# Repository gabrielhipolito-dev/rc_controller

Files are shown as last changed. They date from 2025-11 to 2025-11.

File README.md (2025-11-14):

# Garden Assistant Bot (GAB)

This project includes a robot which uses a variety of sensors & motors to measure and provide data from your garden plants, as well as a user interface for communicating and controlling the robot.

---

##  Visual Overview of GAB Project

### WPF User Interface (UI)
<br>

<p align="center">
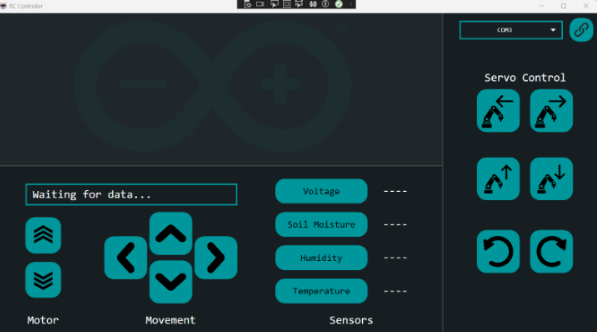
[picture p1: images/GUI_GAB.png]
WPF User Interface for Robot Control & Plant Monitoring
  
  <br>
  <em>Fig. 1 — WPF User Interface for Robot Control & Plant Monitoring</em><br>
  The UI provides control, Bluetooth connection status, and sensor data for soil moisture, temperature, and humidity.
</p>
<br><br>

### GAB  Overview
<br>

<p align="center">
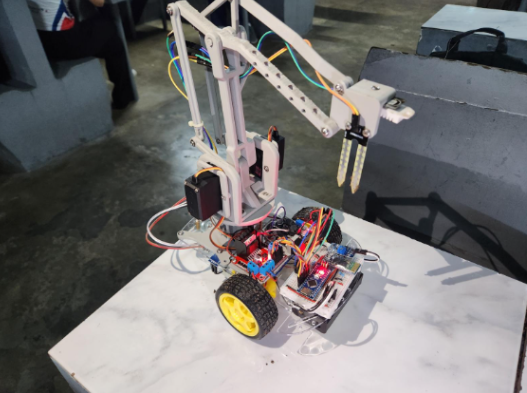
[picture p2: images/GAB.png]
View of Garden Assistant Bot (GAB)
    
  <br>
  <em>Fig. 2 — VIEW Garden Assistant Bot (GAB) Hardware</em><br>
  This figure displays the GAB, showing the sensor placements and main control board.
</p>
<br>

---
### Developed By
- Jeff Bayhon  
- Lance Dador  
- Giuliano de Guzman  
- Gabriel Hipolito  

---

## Languages Used
- **Arduino** (Nano microcontroller firmware)
- **C#** (Windows .NET Application)

---

## Features
- 2-Wheel Drive movement system  
- 4-DOF robotic servo arm  
- Bluetooth communication (Serial)  
- Live sensor readings:
  - Battery voltage  
  - Soil moisture  
  - Air humidity  
  - Air temperature  
- GUI desktop controller
- Keyboard controls for easy operation

---

## Requirements

### Software
- **Visual Studio 2022**
- **.NET 8**
- **Arduino IDE**

### Hardware
- Arduino Nano CH340 
- HC-05 Bluetooth Module 
- L298N Motor Driver 
- 3x MG996R Servo Motor 
- Voltage Sensor Module 
- DHT22 Sensor 
- L298N H-Bridge Driver
- HW-080 soil moisture sensor 
- 2x 18650 Battery Cell
- 2 cell 18650 battery holder
- Toggle Switch 
- Jumper Wires 

---

##  Folder Structure

```
/rc_controller
  └── /ARDUINO_NANO
      └── lupa_tusok_updated_ver.ino
  └── /img
  └── app.xaml
  └── app.xaml.cs
  └── AssemblyInfo.cs
  └── MainWindow.xaml
  └── MainWindow.xaml.cs
  └── rc_controller.csproj
```

## Steps to Connect and the Program

1. Clone the repository:

```bash
git clone https://github.com/YourRepoHere/rc_controller.git
cd rc_controller
```

2. Upload Arduino:

   * Open `/ARDUINO_NANO/lupa_tusok_updated_ver.ino` in Arduino IDE
   * Connect Arduino Nano via USB
   * Select board: `Tools → Board → Arduino Nano`
   * Select processor: `ATmega328P (Old Bootloader)` (for CH340)
   * Select COM port (example: COM5)
   * Click **Upload**
3. Run the Application(Visual Studio):

   * Open `rc_controller.csproj` in Visual Studio
   * Open `MainWindow.xaml`
   * Click **Start / Run** to launch the app
4. Connect to the RC Car:

   * Select Bluetooth COM port in the app
   * Click **Connect**
   * Use the GUI to drive the robot and monitor sensor data

## Notes

* Ensure the robot is powered **before** connecting the app
* Use correct COM port for Bluetooth (not USB after upload)
* Place soil sensor in the plant soil for accurate readings

## How to Run 

1. Pair your PC with the robot via **Bluetooth**
2. Check the COM port assigned to the Bluetooth module (Device Manager)
3. Open the desktop app
4. Select the COM port and click connect
5. Control the robot using the on-screen buttons or keyboard shortcuts below:

### Keyboard Controls

| Function | Keys |
|---|---|
Forward / Back / Left / Right (For Motor Movement) | `W` `S` `A` `D`  
Decrease Motor Speed / Increase Motor Speed | `Z` / `C`  
Battery Reading | `V`  
Soil Moisture Reading | `B`  
Humidity Reading | `N`  
Temperature Reading | `M`  

### Servo Arm Controls

| Servo | Keys |
|---|-----|
Servo A (X - AXIS) | `T` / `G`  
Servo B (Y - AXIS) | `Y` / `H`  
Servo R (Z - ROTATION) | `U` / `I`  

---

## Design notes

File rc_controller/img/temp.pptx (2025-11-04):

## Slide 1

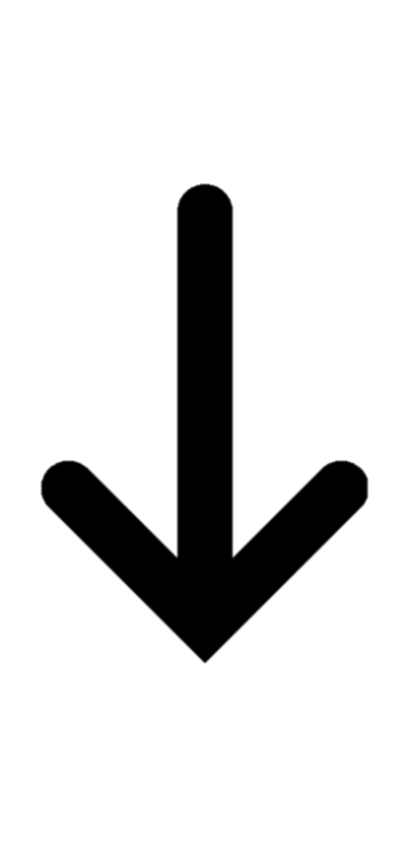
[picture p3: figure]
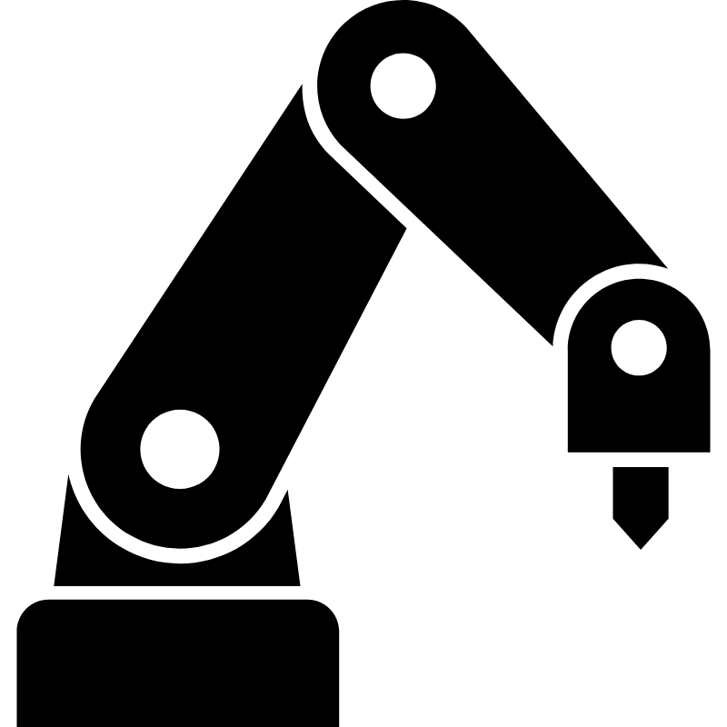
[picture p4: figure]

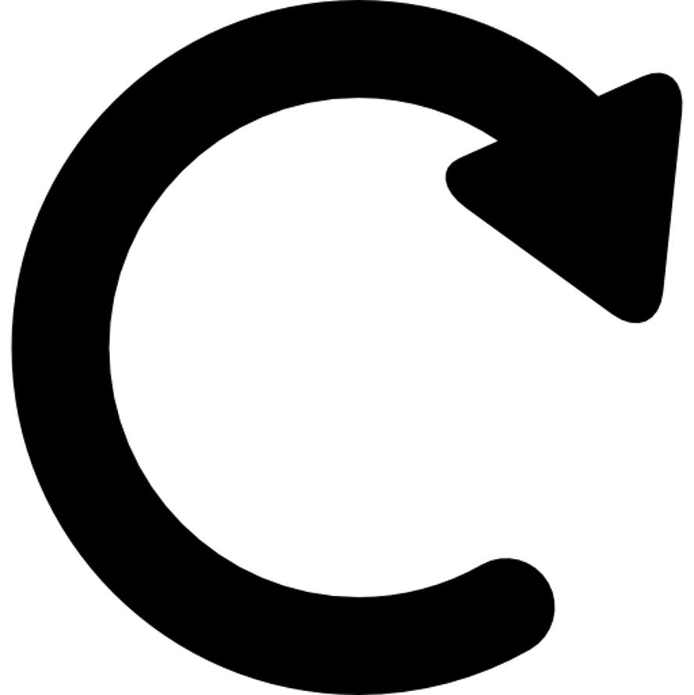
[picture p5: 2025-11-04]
rc_controller/img/rotate-right.png

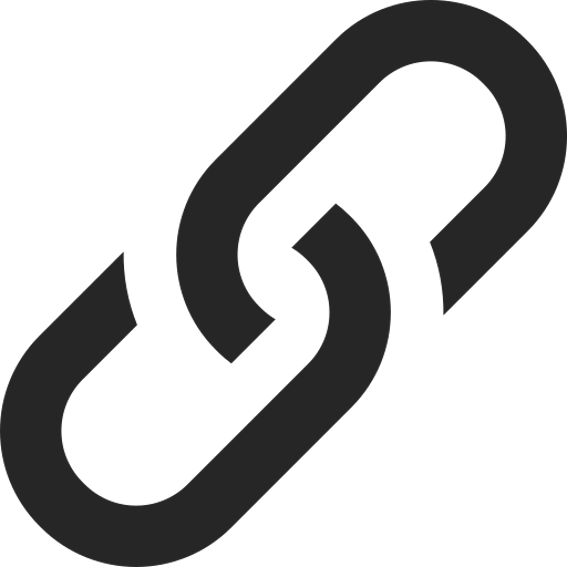
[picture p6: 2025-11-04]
rc_controller/img/connect.png

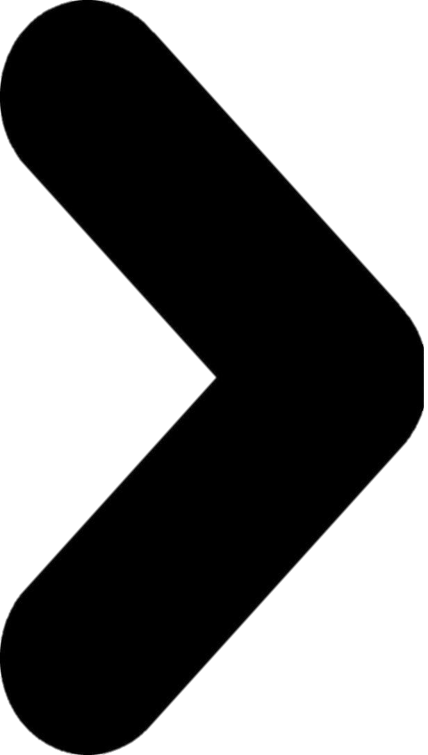
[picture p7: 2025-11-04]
rc_controller/img/arrow-right.png

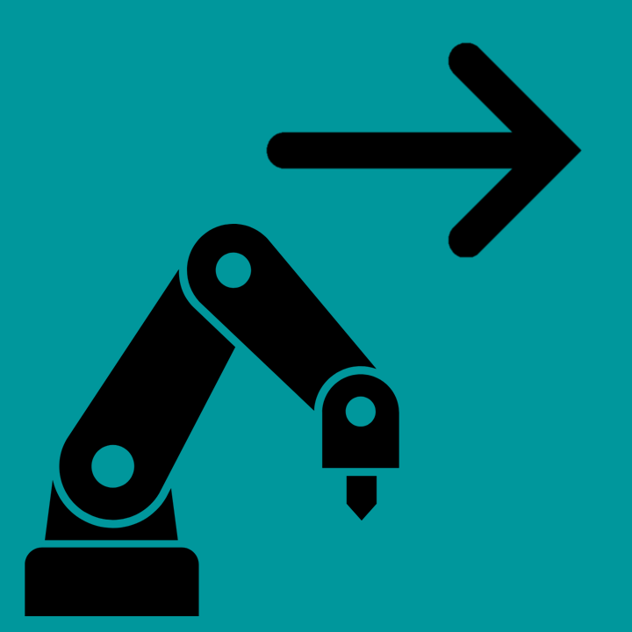
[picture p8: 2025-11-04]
rc_controller/img/arm-forward.png

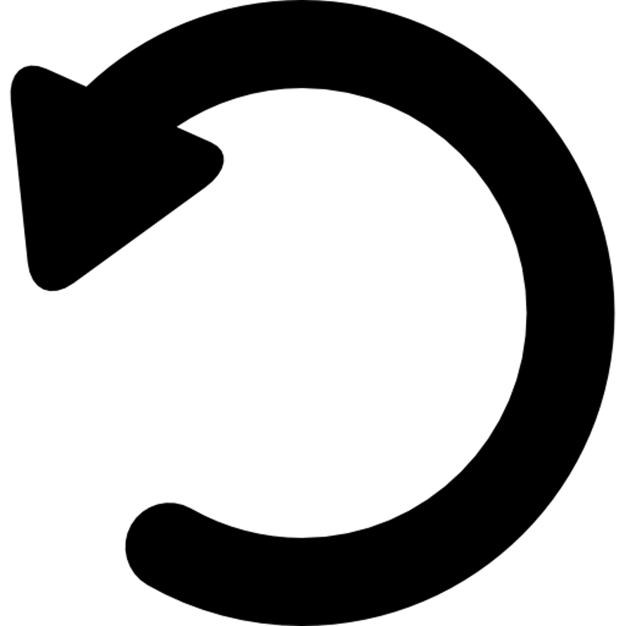
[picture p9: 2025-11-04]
rc_controller/img/rotate-left.png

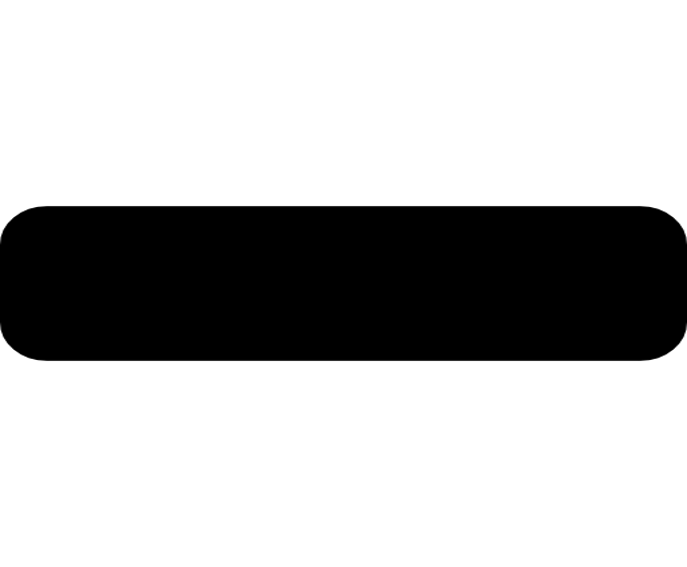
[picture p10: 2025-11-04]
rc_controller/img/minus.png

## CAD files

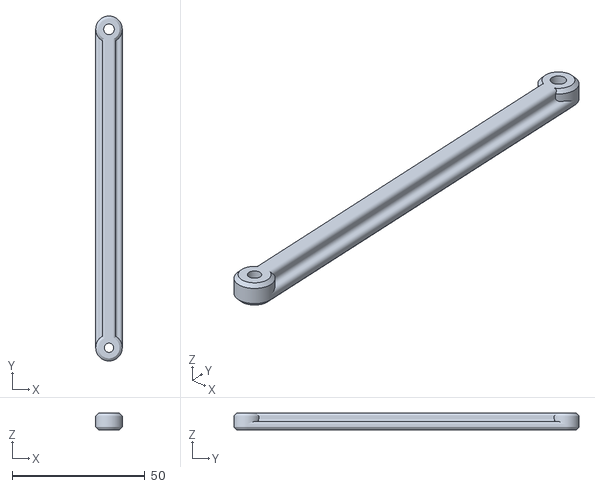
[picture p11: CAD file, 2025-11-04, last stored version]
rc_controller/3D parts/ara-another-robot-arm-model_files/Arms & Base/Arm_B2.stl
10.0 x 130.0 x 6.25

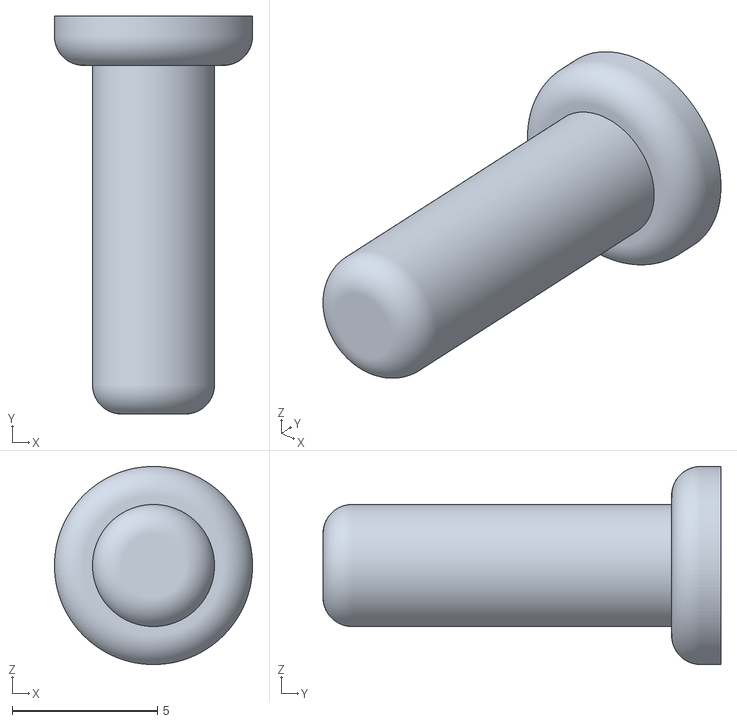
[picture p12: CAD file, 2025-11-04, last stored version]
rc_controller/3D parts/ara-another-robot-arm-model_files/End Effector/Gripper_ServoArm - Part 2.stl
6.82 x 13.7 x 6.82

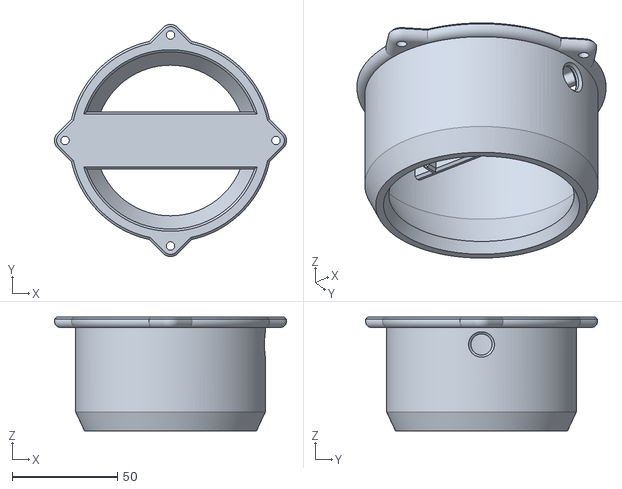
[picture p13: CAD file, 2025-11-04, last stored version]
rc_controller/3D parts/ara-another-robot-arm-model_files/Arms & Base/MountPlate - BaseCover.stl
110.0 x 110.0 x 54.0

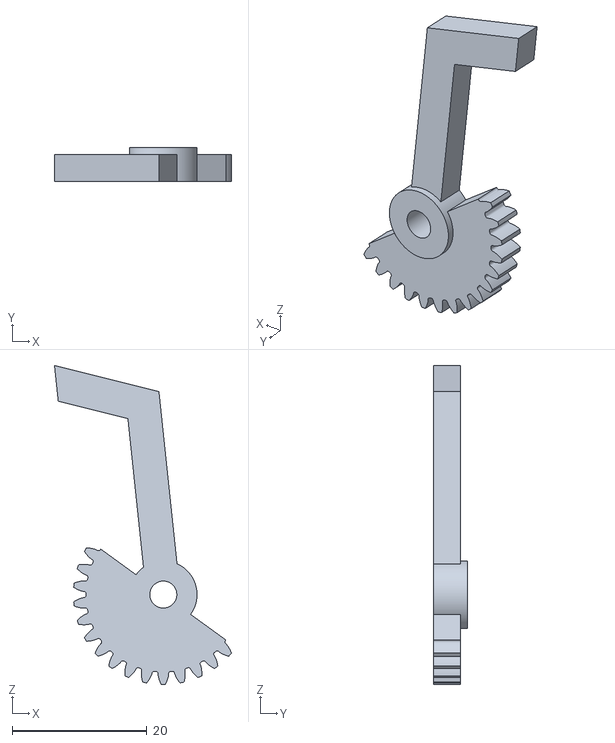
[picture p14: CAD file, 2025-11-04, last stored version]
rc_controller/3D parts/ara-another-robot-arm-model_files/End Effector/Grip_G2_Left.stl
26.2 x 5.00 x 47.3

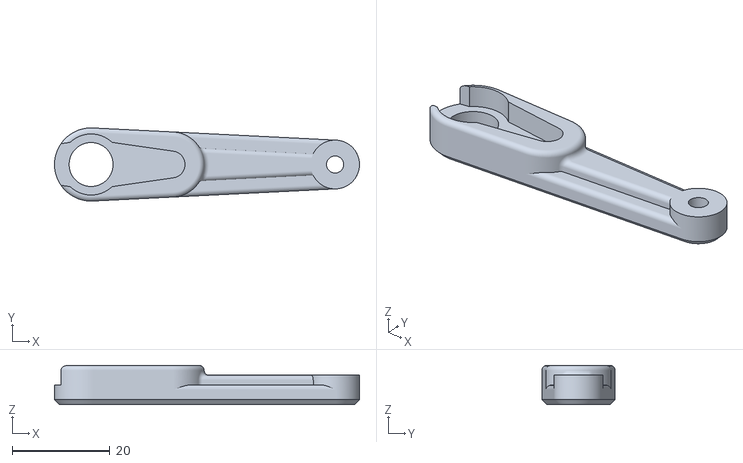
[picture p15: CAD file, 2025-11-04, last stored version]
rc_controller/3D parts/ara-another-robot-arm-model_files/Arms & Base/Arm_B1.stl
62.5 x 15.0 x 8.00

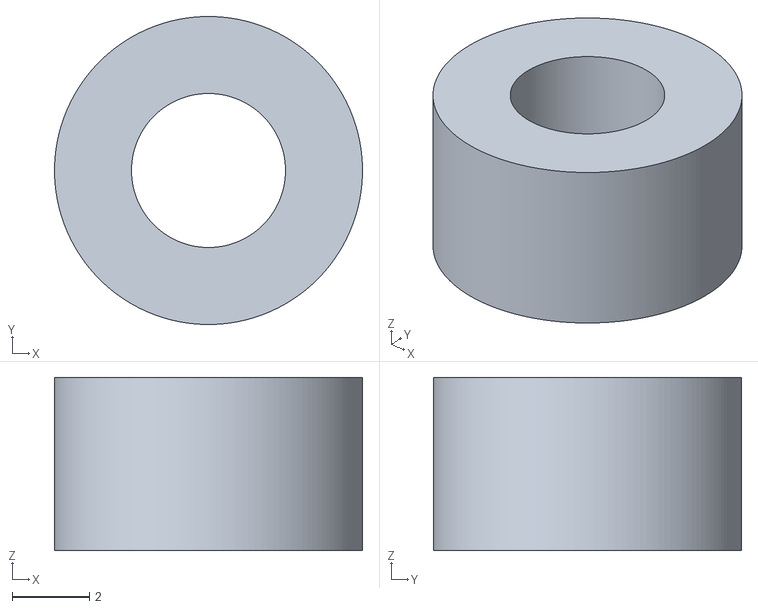
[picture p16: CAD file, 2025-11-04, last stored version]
rc_controller/3D parts/ara-another-robot-arm-model_files/End Effector/Spacer small.stl
8.00 x 8.00 x 4.50

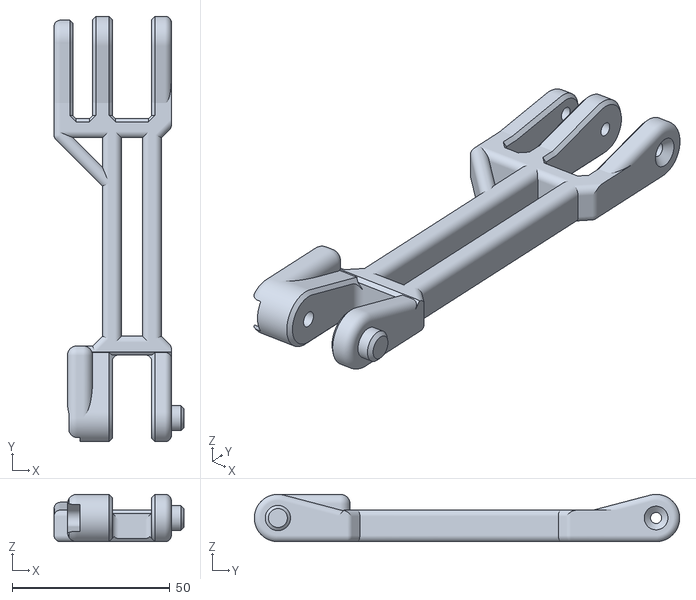
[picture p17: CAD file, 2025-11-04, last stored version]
rc_controller/3D parts/ara-another-robot-arm-model_files/Arms & Base/Arm_A1.stl
41.2 x 135.0 x 15.0

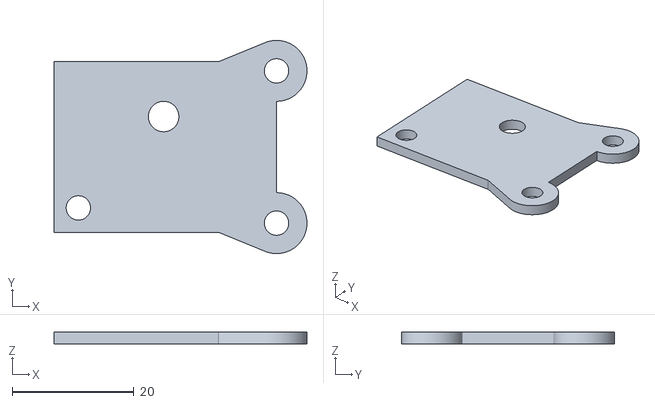
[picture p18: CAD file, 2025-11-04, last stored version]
rc_controller/3D parts/ara-another-robot-arm-model_files/End Effector/Grip_base - Part 2.stl
41.5 x 35.0 x 2.00

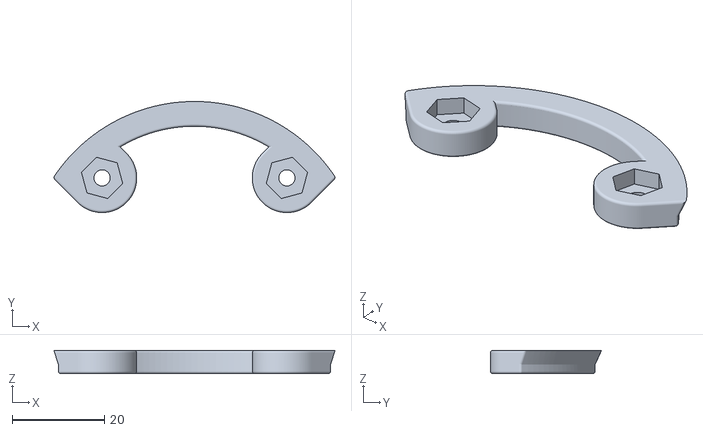
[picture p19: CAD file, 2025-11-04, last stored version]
rc_controller/3D parts/ara-another-robot-arm-model_files/Arms & Base/MountPlate - BaseClip.stl
60.8 x 24.0 x 5.00

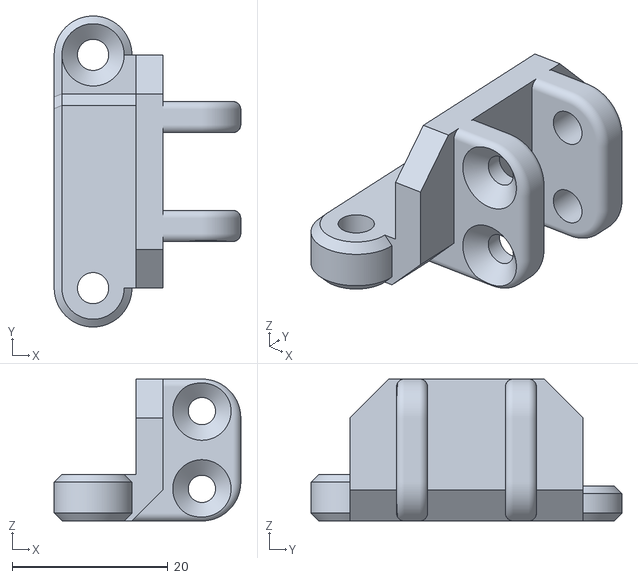
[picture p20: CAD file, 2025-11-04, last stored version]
rc_controller/3D parts/ara-another-robot-arm-model_files/End Effector/Grip_Plate_2.stl
24.0 x 40.0 x 18.3

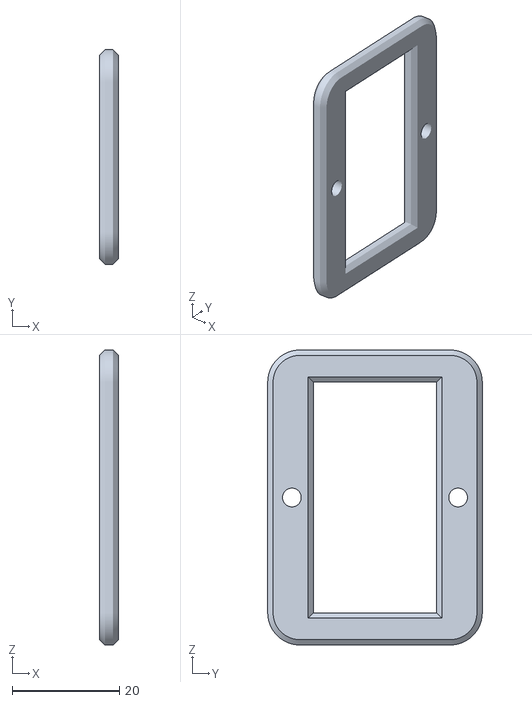
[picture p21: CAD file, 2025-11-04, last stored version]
rc_controller/3D parts/ara-another-robot-arm-model_files/Arms & Base/Base - Hub.stl
3.50 x 40.0 x 55.0

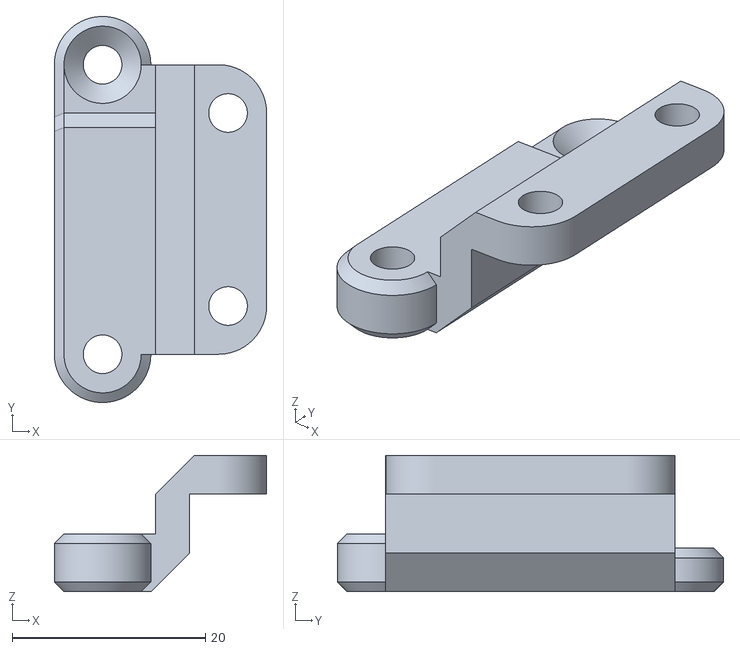
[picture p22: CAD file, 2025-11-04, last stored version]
rc_controller/3D parts/ara-another-robot-arm-model_files/End Effector/Grip_Plate_1.stl
22.0 x 40.0 x 14.1

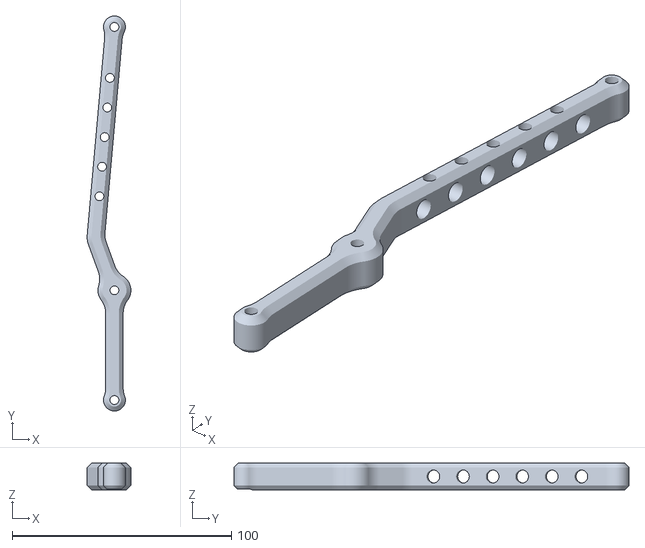
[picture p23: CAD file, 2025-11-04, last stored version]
rc_controller/3D parts/ara-another-robot-arm-model_files/Arms & Base/Arm_A2.stl
20.0 x 180.0 x 12.2

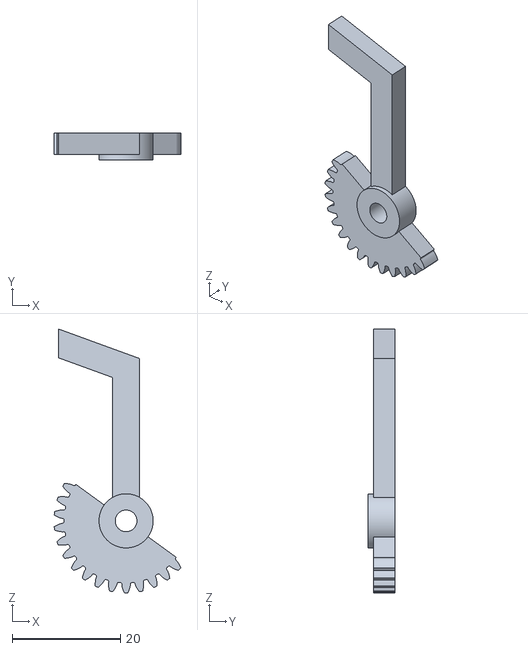
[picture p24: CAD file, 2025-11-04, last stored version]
rc_controller/3D parts/ara-another-robot-arm-model_files/End Effector/Grip_G2_Right.stl
23.4 x 5.00 x 48.8

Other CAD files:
rc_controller/3D parts/ara-another-robot-arm-model_files/Arms & Base/Arm_C2 Triangle.stl
rc_controller/3D parts/ara-another-robot-arm-model_files/End Effector/Gripper_ServoArm - Part 1.stl
rc_controller/3D parts/ara-another-robot-arm-model_files/Arms & Base/MountPlate - BasePlate.stl
rc_controller/3D parts/ara-another-robot-arm-model_files/End Effector/Grip_base - Part 1.stl
rc_controller/3D parts/ara-another-robot-arm-model_files/Arms & Base/Arm_C3.stl
rc_controller/3D parts/ara-another-robot-arm-model_files/Arms & Base/Base.stl

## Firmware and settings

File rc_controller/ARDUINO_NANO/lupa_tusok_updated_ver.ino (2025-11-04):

// C++ code
// Dador_PC = COM8 USB, COM10 BT
// Gab laptop = COM5 USB, COM4 BT
#include <Servo.h>
#include <DHT.h>
#define DHTTYPE DHT22

// motor config
const int enA = 5, enB = 6, in4 = 7, in3 = 8, in2 = 9, in1 = 10;
int msI = 2;
int motorSpdL[] = {0, 130, 185, 252};
int motorSpdR[] = {0, 153, 210, 253}; // adjusted to ensure approximately same voltage level at each motor

// sensor config
const int battPin = A0, soilPin = A3, soilVCC = A4, dhtPin = A2;
float temp = 0.0, hum = 0.0;
DHT dht(dhtPin, DHTTYPE);

// servo config
const int servoA = 4, servoB = 3, servoR = 2, l_limit = 55, u_limit = 195;
int sA = 140, sB =35,sR = 90, gap = 4;
bool sA_up = false, sA_down = false, sB_up = false, sB_down = false, sR_up = false, sR_down = false;
Servo myServoA, myServoB, myServoR;



void setup()
{
  Serial.begin(9600);
  dht.begin();
  
  int out[] = {soilVCC, in1, in2, in3, in4, enA, enB};
  for (int i=0; i<7; i++){
    pinMode(out[i], OUTPUT);
  }
  
  int inp[] = {battPin, soilPin};
  for (int i=0; i<2; i++){
    pinMode(inp[i], INPUT);
  }
  
  myServoA.write(sA);
  myServoA.attach(servoA);
  myServoB.write(sB);
  myServoB.attach(servoB);
  myServoR.attach(servoR);
}

void loop()
{
  if (Serial.available() > 0) {
    // read the incoming serial command:
    char serialData = Serial.read();
    
    switch (serialData){
      // v, battery, b=moisture, n=humidity, m=temperature
      case 'v':{       
      	checkBatt();
      	break;
        }
      case 'b':{
      	checkMoisture();
      	break;
        }
      case 'n':{
      	checkHum();
      	break;
        }
      case 'm':{
      	checkTemp();
      	break;
        }
      // wasd for direction control
      case 'w':{
        int a[] = {0, 1, 0, 1}, b[] = {1, 1};
      	move_motor(a, b, "Direction: Forward");
      	break;
        }
      case 'a':{
        int a[] = {0, 1, 1, 0}, b[] = {1, 0};
      	move_motor(a, b, "Direction: Left");
      	break;
        }
      case 's':{
        int a[] = {1, 0, 1, 0}, b[] = {1, 1};
      	move_motor(a, b, "Direction: Backward");
      	break;
      }
      case 'd':{
        int a[] = {1, 0, 0, 1}, b[] = {0, 1};
      	move_motor(a, b, "Direction: Right");
      	break;
      }
      // z=lower speed, x=stop, c=increase speed
      case 'x':{
      	stop();
      	break;
      }
      case 'z':{
        if (0<msI && msI<=3){
          msI--;
          Serial.println("Motor Speed: " + String(msI)+ "/3");
        }
      	break;
      }
      case 'c':{
      	if (0<=msI && msI<3){
          msI++;
          Serial.println("Motor Speed: " + String(msI)+ "/3");
        }
      	break;
      }
      // t/g = servo A, y/h = servo B, u/i = servo R
      case 't': {
        sA_down = true, sA_up = false;
        Serial.println("Servo arm going forward");
        break;
      }
      case 'g': {
        sA_up = true, sA_down = false;
        Serial.println("Servo arm going backward");
        break;
      }
      case 'y': {
        sB_down = true, sB_up = false;
        Serial.println("Servo arm going up");
        break;
      }
      case 'h': {
        sB_up = true, sB_down = false;
        Serial.println("Servo arm going down");
        break;
      }
      case 'u': {
        sR_up = true, sR_down = false;
        Serial.println("Servo arm turning counterclockwise");
        break;
      }
      case 'i': {
        sR_down = true, sR_up = false;
        Serial.println("Servo arm turning clockwise");
        break;
      }
      case 'p':{
        sA_up = sA_down = sB_up = sB_down = sR_up = sR_down = false;
        Serial.println("All servos stopped");
        break;
      }
    }
  }

  // perform servo movement
  if (sA_down) {
    if ((sA - gap) + sB <= u_limit && (sA - gap) + sB >= l_limit) // check relative angle between servo A & B: (30 < angle < 150) to prevent arm damage
      moveServo(0, 180, 0, sA, myServoA);
  }
  else if (sA_up) {
    if ((sA + gap) + sB <= u_limit && (sA + gap) + sB >= l_limit)
      moveServo(0, 180, 1, sA, myServoA);
  }

  if (sB_down) {
    if (sA + (sB - gap) <= u_limit && sA + (sB - gap) >= l_limit)
      moveServo(0, 125, 0, sB, myServoB);
  }
  else if (sB_up) {
    if (sA + (sB + gap) <= u_limit && sA + (sB + gap) >= l_limit)
      moveServo(0, 125, 1, sB, myServoB);
  }
  
  if (sR_down){
    moveServo(0,180, 0, sR, myServoR);
  }
  else if (sR_up){
    moveServo(0,180, 1, sR, myServoR);
  }

  delay(100);
}

// ---------------------------------------------- // 
void checkBatt(){
  float fivevoltpinval = 5.0;
  float batt = (analogRead(battPin)*5*fivevoltpinval/1024.00)+0.04;
  Serial.println(String(batt));
  return;
}

void checkMoisture(){
  // wet = 386, dry = 1007;

  digitalWrite(soilVCC, HIGH);
  delay(50);
  float moist = analogRead(soilPin);
  float moistval = 100.00 - 100*(moist-386)/(1007-386);
  Serial.println(String(constrain(moistval, 0, 100)));
  delay(250);
  digitalWrite(soilVCC, LOW);
  return;
}

void checkTemp(){
  temp = dht.readTemperature();
  Serial.println(String(temp));
  return;
}

void checkHum(){
  hum = dht.readHumidity();
  Serial.println(String(hum));
  return;
}

// ---------------------------------------------- // 

void move_motor(int dirVal[], int mVal[] , String msg){
  int motorpins[] = {in1, in2, in3, in4};

  for (int i=0; i<4; i++){
    digitalWrite(motorpins[i], dirVal[i]);
  }
  analogWrite(enA, mVal[0]*motorSpdR[msI]);
  analogWrite(enB, mVal[1]*motorSpdL[msI]);
  Serial.println(msg);
}

void stop(){
  analogWrite(enA, 0);
  analogWrite(enB, 0);
  Serial.println("Stopped Motors");
  return;
}

// ---------------------------------------------- // 

void moveServo(int l_limit, int u_limit, int val, int &sVal, Servo &sName){
  if (val && sVal<u_limit){
    sVal+=gap;
  }
  else if (!val && l_limit<sVal){
    sVal-=gap;
  }
  sName.write(sVal);
}

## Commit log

2025-10-27 Enhance UI for sensor readings and servo controls
    Updated `MainWindow.xaml` to include new UI elements for displaying sensor readings (battery voltage, soil moisture, temperature, humidity) and servo controls. Added `Image`, `TextBlock`, `ProgressBa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
    Implemented `InitializeSensorReading` method in `MainWindow.xaml.cs` for serial port communication and data processing. New event handlers for servo control and measurement buttons have been added.
    Updated project file to remove an unused image and include a new screenshot image. Added a new PNG image for visual representation in the UI.
    These changes improve functionality and user experience by integrating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
2025-10-28 Enhance RC Controller UI and Serial Communication
    Updated MainWindow.xaml to add control buttons for the RC vehicle and display sensor data. Refactored MainWindow.xaml.cs for improved serial communication handling, including new methods for button interactions and enhanced error handling. Changed the COM port for the SerialPort initialization and ensured UI updates correctly based on received sensor data.
2025-10-28 Revamp UI with servo controls and layout adjustments
    Updated `MainWindow.xaml` to reposition buttons and add new servo control buttons with event handlers. Adjusted text box layouts for better alignment.
    Enhanced `MainWindow.xaml.cs` with new methods for servo button interactions, maintaining existing functionality for voltage and humidity readings.
2025-10-29 Improve UI layout and resource management
    Updated MainWindow.xaml to enhance UI elements, including
    button alignment, ComboBox styling, and sensor display
    positions. Adjusted the CONNECT button and added more
    options to the COM port selection.
    Modified rc_controller.csproj to include mater_car.png
    as a project resource, ensuring it is part of the application
    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
2025-10-30 Edit: edit some button and textbox
2025-11-03 UPDATE: READ.md
    Updated servo control keys in the README.
2025-11-04 Remove WPF theming support from AssemblyInfo.cs
    Deleted the `using System.Windows;` directive and the
    ThemeInfo assembly attribute, indicating the project
    no longer utilizes WPF theming features.
2025-11-04 Add WPF application structure and theme information
    Updated App.xaml to define application class and resources.
    Modified App.xaml.cs to include namespaces and interaction logic.
    Adjusted AssemblyInfo.cs to reference System.Windows and specify theme resource locations.
2025-11-04 Enhance UI styles and improve serial communication logic
    Updated `MainWindow.xaml` to reorganize and enhance button and combo box styles, improving visual appearance and interactivity. Adjusted layout for consistency and usability.
    Modified `MainWindow.xaml.cs` to add delays for Arduino communication and refined thresholds for sensor feedback in `VoltageTextBox` and `MoistureTextBox`. Added a placeholder event handler for `Humi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
2025-11-04 3d printing parts
    [Arm_A1.stl, Arm_A2.stl, Arm_B1.stl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]
2025-11-04 Enhance motor and sensor control functionality
    Updated code to include motor control, servo control, and sensor readings. Added libraries for servo and DHT sensors, defined constants for motor speeds and sensor pins. Improved `setup()` and `loop(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
2025-11-04 remove files
    [Arm_A1.stl, Arm_A2.stl, Arm_B1.stl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]
